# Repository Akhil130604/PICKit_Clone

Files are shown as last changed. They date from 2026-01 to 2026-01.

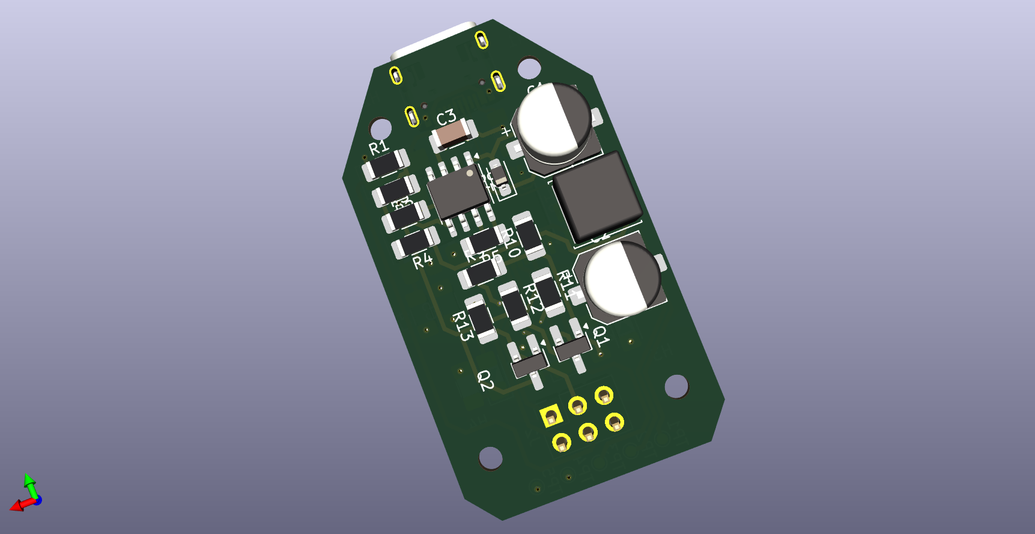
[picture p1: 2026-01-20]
screenshots/Screenshot 2026-01-21 011726.png

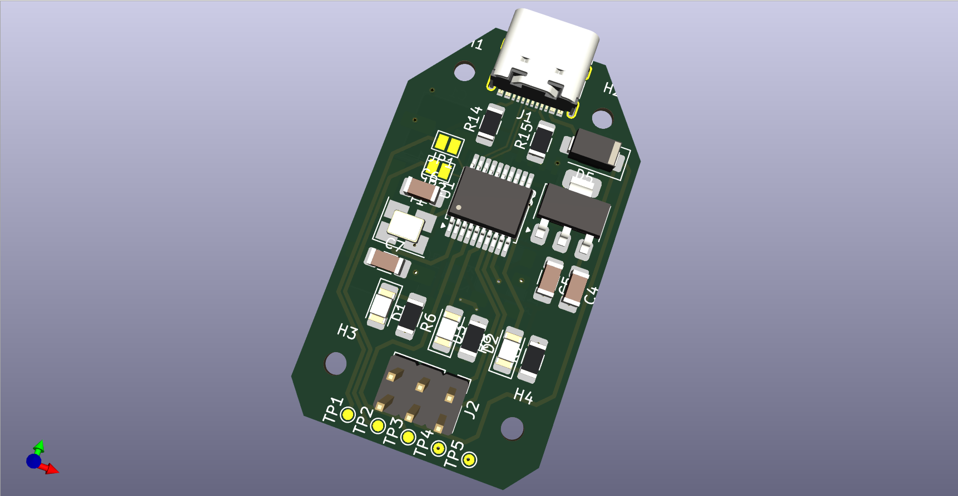
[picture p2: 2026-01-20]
screenshots/Screenshot 2026-01-21 011709.png

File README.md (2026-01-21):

# PICKit Clone #
📖 About The Project

This project aims to build a fully open-source, cost-effective clone of the Microchip PICKit programmer/debugger. While the original PICKit is a standard tool for PIC microcontrollers, this project seeks to provide a transparent hardware design and firmware implementation that can be studied, modified, and built by the community.

The goal is not just to replicate functionality, but to create a learning platform for embedded programmers and hardware designers interested in:

ICSP (In-Circuit Serial Programming) protocols.

USB Device implementations.

High-voltage generation circuits (VPP).

Low cost hardware.

## ⚠️ Current Status ##

Current Phase: 🚧 Hardware Design & Schematic Capture

We are currently in the initial design phase. The focus is on selecting components, finalizing the power architecture, and routing the initial PCB.

[ ] System Architecture Definition

[ ] Schematic Capture

[ ] PCB Layout

[ ] Prototype Assembly

[ ] Firmware Development

[ ] Testing & Validation

🛠️ Tech Stack & Tools

To view or edit the files, you will need:

EDA Tool: KiCad

Firmware IDE: MPLAB X IDE

## 📂 Repository Structure ##

The repository is currently messed up with unnecesssary files. you are welcome to rearrange it.

Note on Branches:

main: Contains stable, verified releases.

designing: The active design branch. All hardware work happens here.

firmware: The design and development of firmware happens here.

## 🚀 Getting Started ##

Clone the repository:

git clone [https://github.com/Akhil130604/PICKit_Clone.git](https://github.com/Akhil130604/PICKit_Clone.git)

Checkout the branch:

cd PICKit_Clone

git checkout branch

## 🤝 How to Contribute ##

We welcome contributions from the community! Whether it's a code fix, a better PCB routing suggestion, or documentation improvements.

Please read CONTRIBUTING.md for details on our code of conduct and the process for submitting pull requests.

## 📄 License ##

Distributed under the MIT License. See LICENSE for more information.

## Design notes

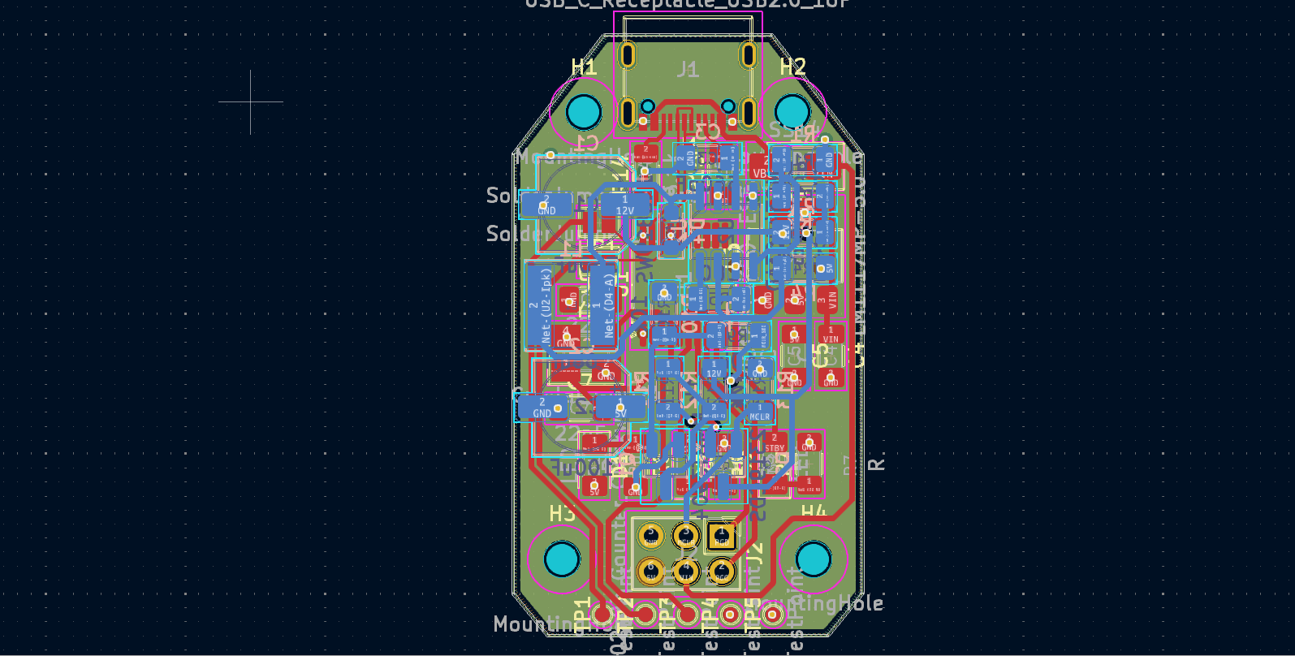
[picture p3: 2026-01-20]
screenshots/Screenshot 2026-01-21 011534.png

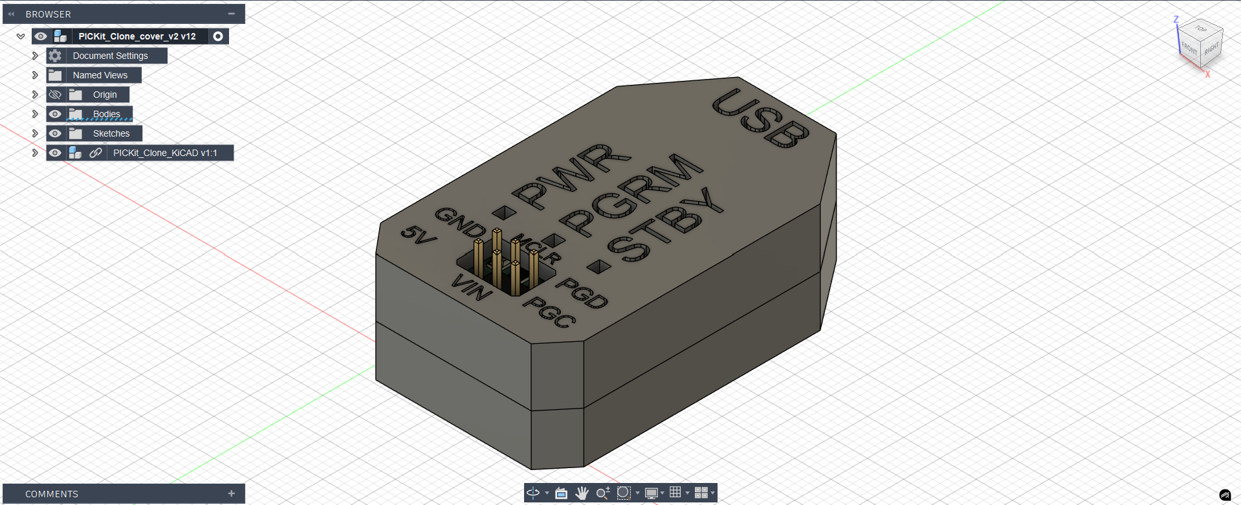
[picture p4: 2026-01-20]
screenshots/Screenshot 2026-01-21 012029.png

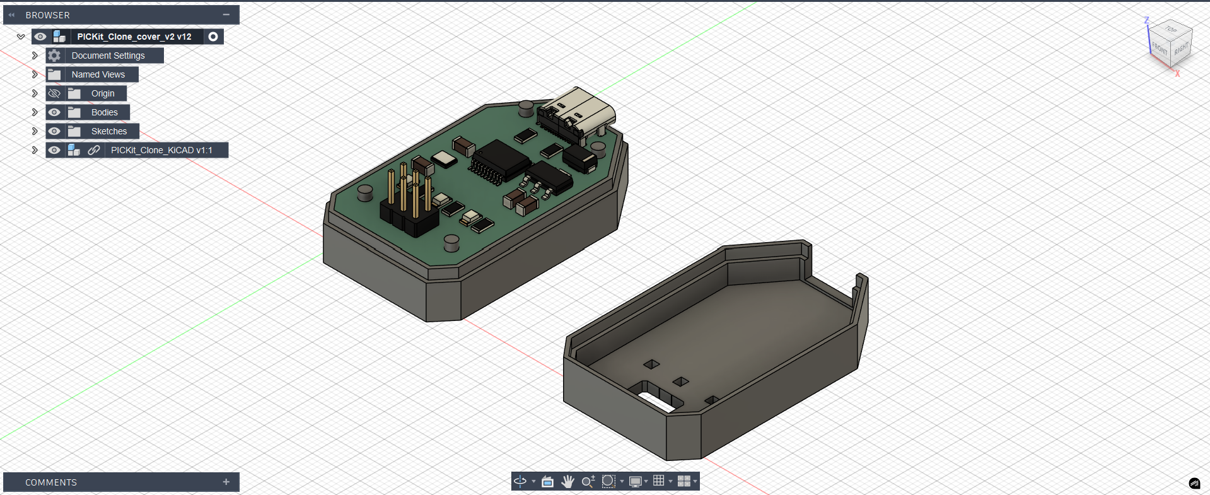
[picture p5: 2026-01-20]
screenshots/Screenshot 2026-01-21 011945.png

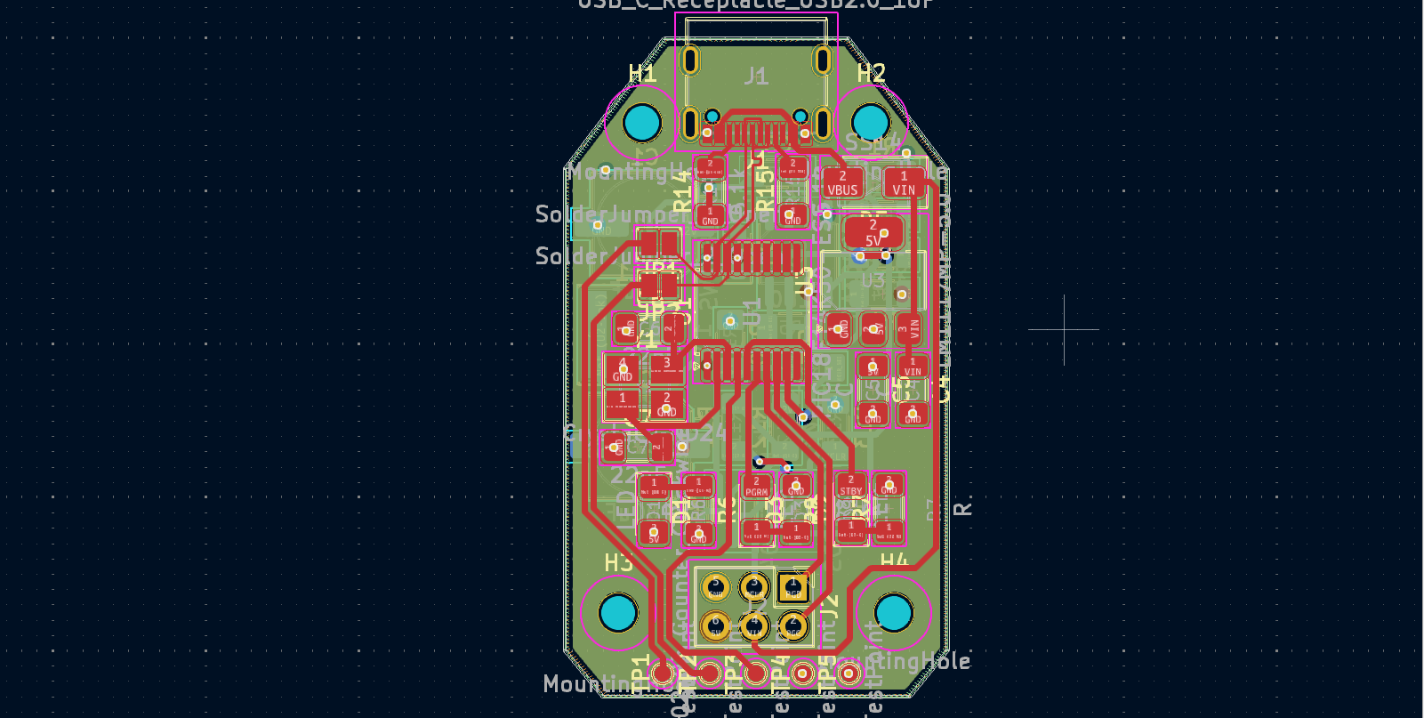
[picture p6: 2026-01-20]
screenshots/Screenshot 2026-01-21 011514.png

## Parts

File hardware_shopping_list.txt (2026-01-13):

PIC Microcontroller:
https://robu.in/product/pic18f14k50-i-ss-microchip-8-bit-mcu-flash-pic18-family-pic18f-k5x-series-microcontrollers-pic18-48-mhz-16-kb-20-pins/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

USB connector
https://robu.in/product/type-c-31-m-31-hroparts-5a-1-surface-mount-right-angle-16p-female-30%E2%84%8380%E2%84%83-type-c-smd-usb-connectors-rohs/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

BOOST Converter
https://robu.in/product/mc34063adr-texas-instruments-adjustable-3v40v-1-5a-soic-8-dc-dc-converters-rohs/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

Inductor
https://evelta.com/68uh-20-1-1a-inductor-smd/?srsltid=AfmBOorUdZxelYheTT5o_TzHN1Lp0D162NHqgf74cKlYZvhE9jBK9WkL

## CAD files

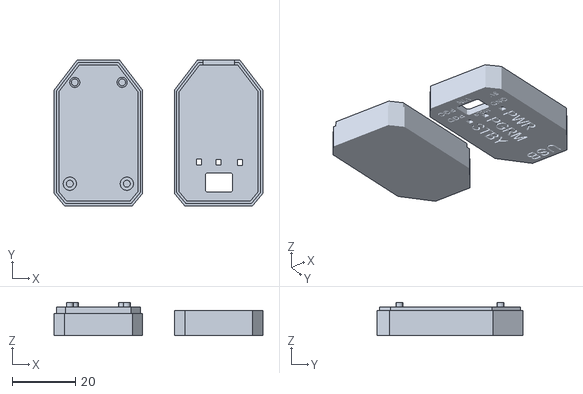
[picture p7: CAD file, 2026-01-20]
PICKit_Clone_Cover/PICKit_Clone_cover_v2.stl
66.0 x 46.0 x 10.5

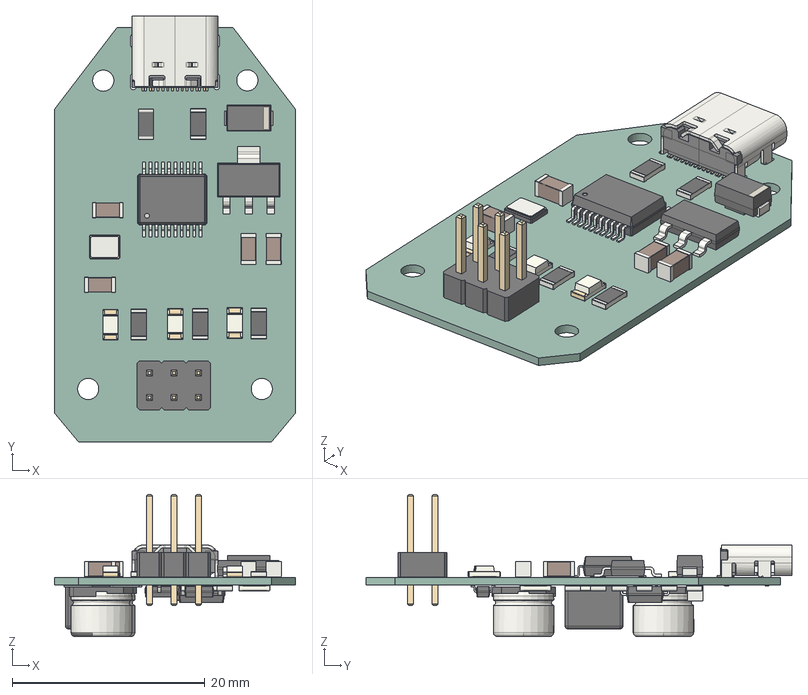
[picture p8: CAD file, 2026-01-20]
PICKit_Clone_KiCAD/PICKit_Clone_KiCAD.step
25.0 x 44.2 x 14.7 mm
C_1206_3216Metric x 5
LED_1206_3216Metric x 3
D_SMA
R_1206_3216Metric x 15
SSOP_20_53x72mm_P065mm
Crystal_SMD_3225-4Pin_3.2x2.5mm_HandSoldering
SOT_223
USB_C_Receptacle_16P_TopMnt_Horizontal_GCT_USB4105-xx-A
PinHeader_2x03_P254mm_Vertical
SOT_23 x 2
CQ assembly
SOIC_8_39x49mm_P127mm
CP_Elec_63x53 x 2
D_SOD_323
PICKit_Clone_KiCAD_PCB

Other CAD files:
PICKit_Clone_Cover/PICKit_Clone_cover_v2.f3z

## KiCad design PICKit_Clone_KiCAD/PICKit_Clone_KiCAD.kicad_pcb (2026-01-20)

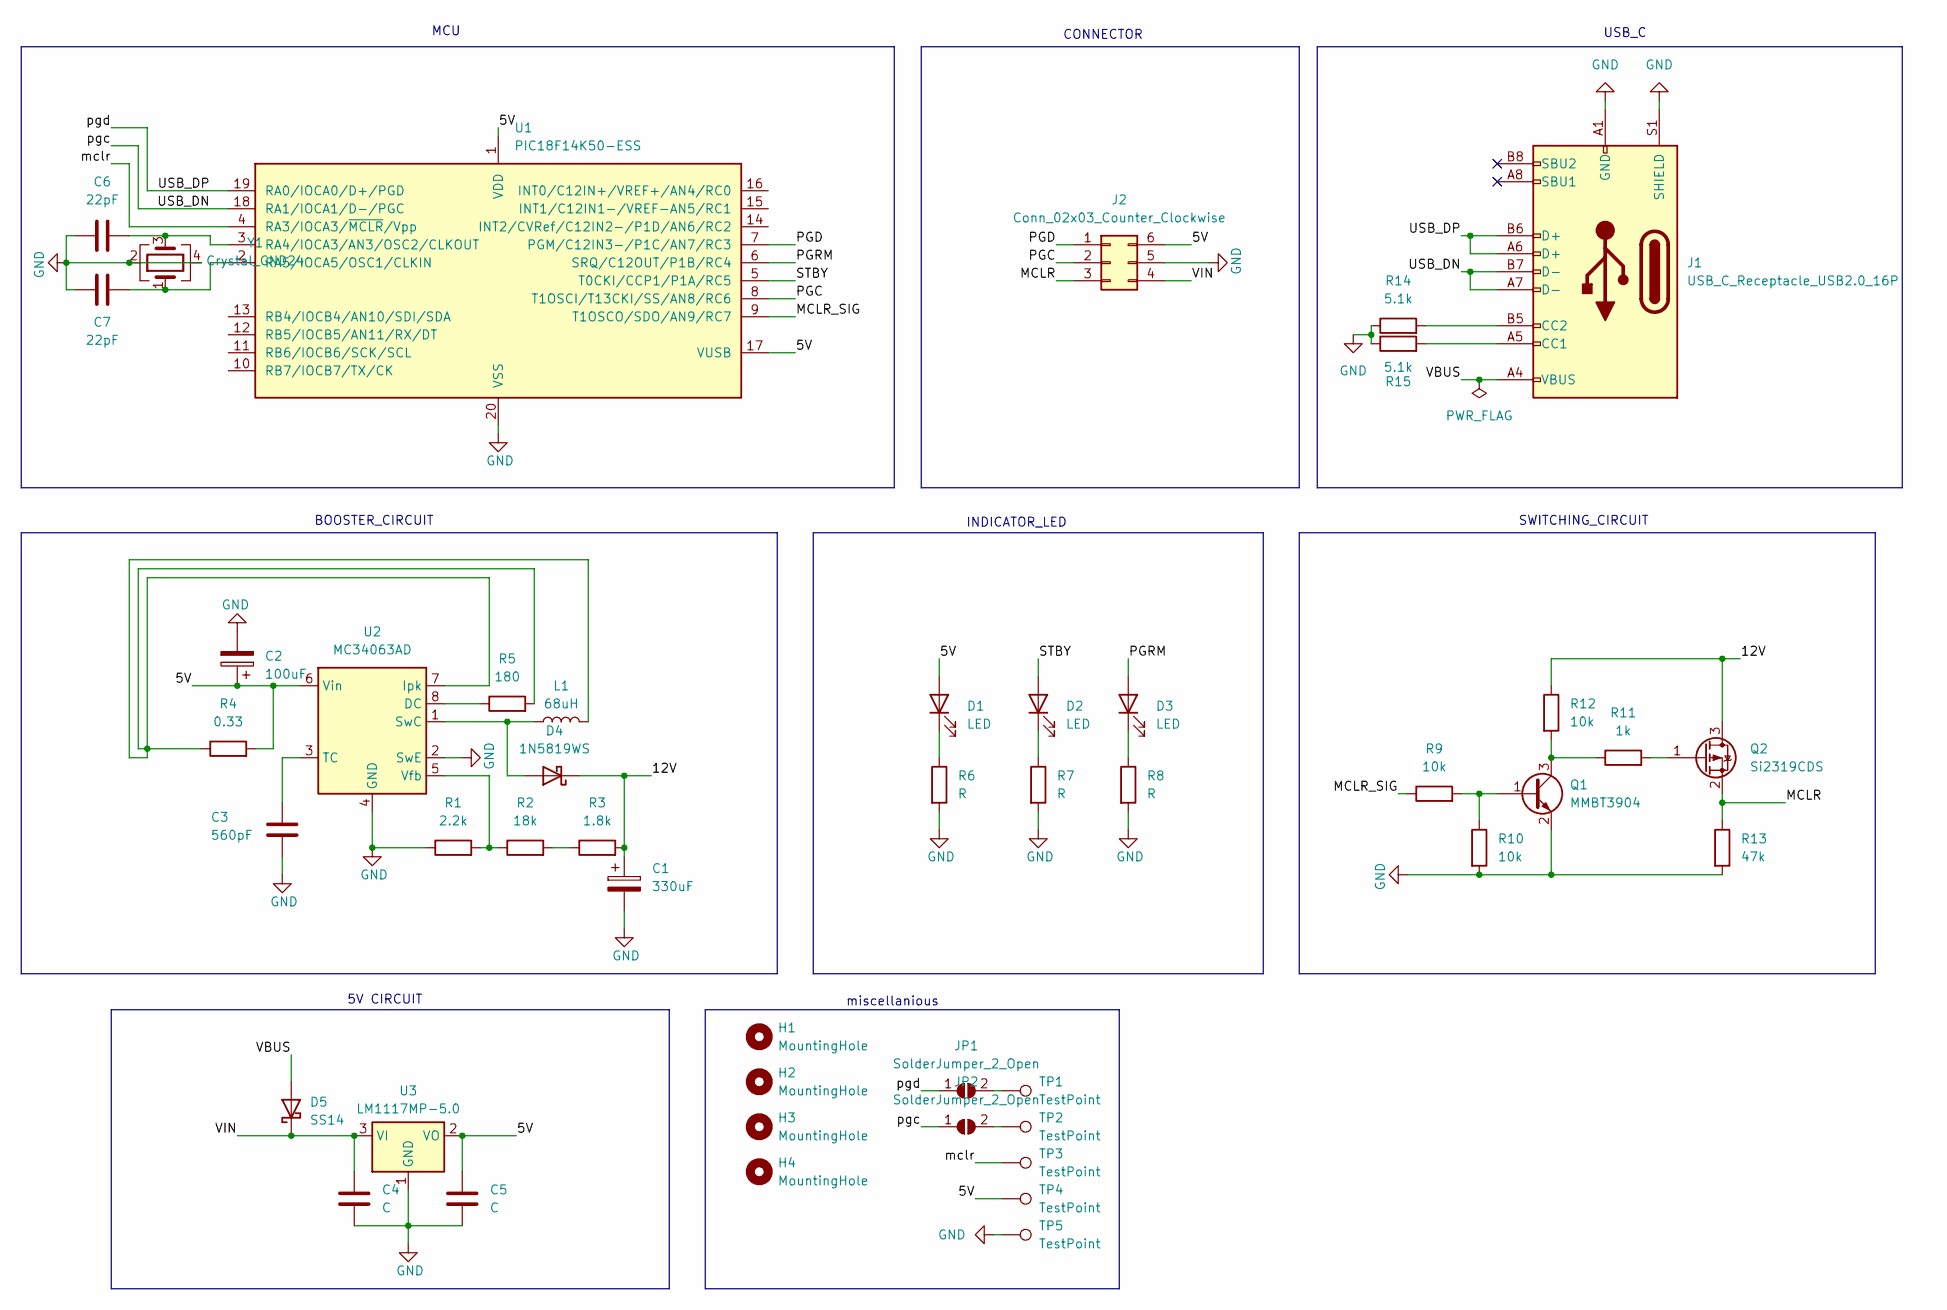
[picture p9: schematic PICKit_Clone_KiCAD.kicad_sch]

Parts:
C1: 330uF; CP_Elec_6.3x5.3
C2: 100uF; CP_Elec_6.3x5.3
C3: 560pF; C_1206_3216Metric_Pad1.33x1.80mm_HandSolder
C4, C5: C; C_1206_3216Metric_Pad1.33x1.80mm_HandSolder
C6, C7: 22pF; C_1206_3216Metric_Pad1.33x1.80mm_HandSolder
D1, D2, D3: LED; LED_1206_3216Metric_Pad1.42x1.75mm_HandSolder
D4: 1N5819WS; D_SOD-323_HandSoldering
D5: SS14; D_SMA
H1, H2, H3, H4: MountingHole; MountingHole_2.2mm_M2
J1: USB_C_Receptacle_USB2.0_16P; USB_C_Receptacle_G-Switch_GT-USB-7010ASV
J2: Conn_02x03_Counter_Clockwise; PinHeader_2x03_P2.54mm_Vertical
JP1, JP2: SolderJumper_2_Open; SolderJumper-2_P1.3mm_Open_Pad1.0x1.5mm
L1: 68uH; L_Sunlord_SWPA6045S
Q1: MMBT3904; SOT-23_Handsoldering
Q2: Si2319CDS; SOT-23_Handsoldering
R1: 2.2k; R_1206_3216Metric_Pad1.30x1.75mm_HandSolder
R2: 18k; R_1206_3216Metric_Pad1.30x1.75mm_HandSolder
R3: 1.8k; R_1206_3216Metric_Pad1.30x1.75mm_HandSolder
R4: 0.33; R_1206_3216Metric_Pad1.30x1.75mm_HandSolder
R5: 180; R_1206_3216Metric_Pad1.30x1.75mm_HandSolder
R6, R7, R8: R; R_1206_3216Metric_Pad1.30x1.75mm_HandSolder
R9, R10, R12: 10k; R_1206_3216Metric_Pad1.30x1.75mm_HandSolder
R11: 1k; R_1206_3216Metric_Pad1.30x1.75mm_HandSolder
R13: 47k; R_1206_3216Metric_Pad1.30x1.75mm_HandSolder
R14, R15: 5.1k; R_1206_3216Metric_Pad1.30x1.75mm_HandSolder
TP1, TP2, TP3, TP4, TP5: TestPoint; TestPoint_Pad_D1.0mm
U1: PIC18F14K50-ESS; SSOP-20_5.3x7.2mm_P0.65mm
U2: MC34063AD; SOIC-8_3.9x4.9mm_P1.27mm
U3: LM1117MP-5.0; SOT-223-3_TabPin2
Y1: Crystal_GND24; Crystal_SMD_3225-4Pin_3.2x2.5mm_HandSoldering

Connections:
/5V: C2.1, C5.1, D1.2 (A), J2.6, R4.2, TP4.1, U1.1 (VDD), U1.17 (VUSB), U2.6 (Vin), U3.2 (VO)
/12V: C1.1, D4.1 (K), Q2.3 (D), R3.2, R12.1
/MCLR: J2.3, Q2.2 (S), R13.1
/MCLR_SIG: R9.1, U1.9 (T1OSCO/SDO/AN9/RC7)
/PGC: J2.2, U1.8 (T1OSCI/T13CKI/SS/AN8/RC6)
/PGD: J2.1, U1.7 (PGM/C12IN3-/P1C/AN7/RC3)
/PGRM: D3.2 (A), U1.6 (SRQ/C12OUT/P1B/RC4)
/STBY: D2.2 (A), U1.5 (T0CKI/CCP1/P1A/RC5)
/USB_DN: J1.A7 (D-), J1.B7 (D-), JP2.1 (A), U1.18 (RA1/IOCA1/D-/PGC)
/USB_DP: J1.A6 (D+), J1.B6 (D+), JP1.1 (A), U1.19 (RA0/IOCA0/D+/PGD)
/VBUS: D5.2 (A), J1.A4 (VBUS), J1.A9 (VBUS), J1.B4 (VBUS), J1.B9 (VBUS)
/VIN: C4.1, D5.1 (K), J2.4, U3.3 (VI)
/mclr: TP3.1, U1.4 (RA3/IOCA3/~MCLR/Vpp)
GND: C1.2, C2.2, C3.2, C4.2, C5.2, C6.1, C7.1, J1.A1 (GND), J1.A12 (GND), J1.B1 (GND), J1.B12 (GND), J1.S1 (SHIELD), J2.5, Q1.2 (E), R1.1, R6.2, R7.2, R8.2, R10.2, R13.2, R14.1, R15.1, TP5.1, U1.20 (VSS), U2.2 (SwE), U2.4 (GND), U3.1 (GND), Y1.2, Y1.4
unnamed: D1.1 (K), R6.1
unnamed: D2.1 (K), R7.1
unnamed: D3.1 (K), R8.1
unnamed: D4.2 (A), L1.1, U2.1 (SwC)
unnamed: J1.A5 (CC1), R15.2
unnamed: J1.B5 (CC2), R14.2
unnamed: JP1.2 (B), TP1.1
unnamed: JP2.2 (B), TP2.1
unnamed: Q1.1 (B), R9.2, R10.1
unnamed: Q1.3 (C), R11.1, R12.2
unnamed: Q2.1 (G), R11.2
unnamed: R2.2, R3.1
unnamed: C6.2, U1.3 (RA4/IOCA3/AN3/OSC2/CLKOUT), Y1.3
unnamed: C7.2, U1.2 (RA5/IOCA5/OSC1/CLKIN), Y1.1
unnamed: R5.1, U2.8 (DC)
unnamed: L1.2, R4.1, R5.2, U2.7 (Ipk)
unnamed: C3.1, U2.3 (TC)
unnamed: R1.2, R2.1, U2.5 (Vfb)

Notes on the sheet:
USB_C
5V CIRCUIT
SWITCHING_CIRCUIT
INDICATOR_LED
BOOSTER_CIRCUIT
MCU
CONNECTOR
miscellanious

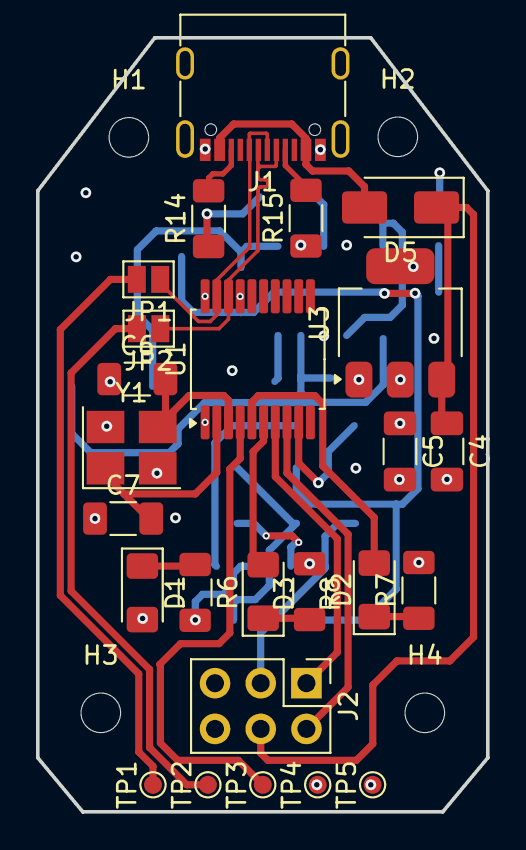
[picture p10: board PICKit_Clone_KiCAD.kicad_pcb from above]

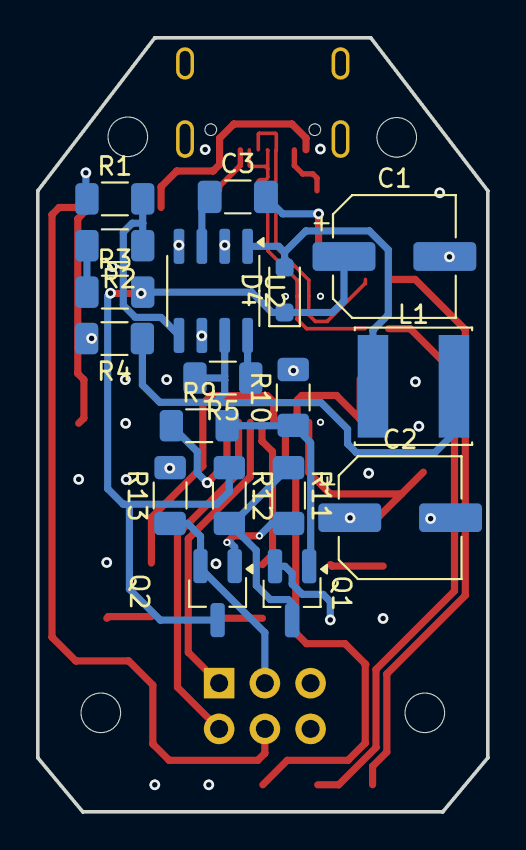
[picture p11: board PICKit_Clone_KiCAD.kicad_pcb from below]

Board: 4 copper layers, 25.0 x 43.0 mm, 47 parts (18 on the bottom side), 32 nets.

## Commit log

2026-01-13 PCB and CAD design
    1)PCB design of the board
    2)CAD design for the cover
    [PICKit_Clone_KiCAD-B_Cu.gbr, PICKit_Clone_KiCAD-B_Mask.gbr, PICKit_Clone_KiCAD-B_Paste.gbr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]
2026-01-20 PCB and Design update
    1) PCB has been modified to include pads for initial programming of the MCU
    2)cover has been modified according to the new size of the PCB
    [PICKit_Clone_KiCAD-B_Cu.gbr, PICKit_Clone_KiCAD-B_Mask.gbr, PICKit_Clone_KiCAD-B_Paste.gbr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]
2026-01-21 Enhance README with project details and guidelines
    Added project overview, current status, tech stack, repository structure, and contribution guidelines to README.
